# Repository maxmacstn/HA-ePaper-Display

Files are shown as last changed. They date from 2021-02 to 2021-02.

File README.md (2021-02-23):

# HA Sensor ePaper Display
E-Paper display for viewing sensor data from Home Assistant. This firmware is based on **ESPhome**, so you need to install ESPhome and compile .yaml file by yourself.

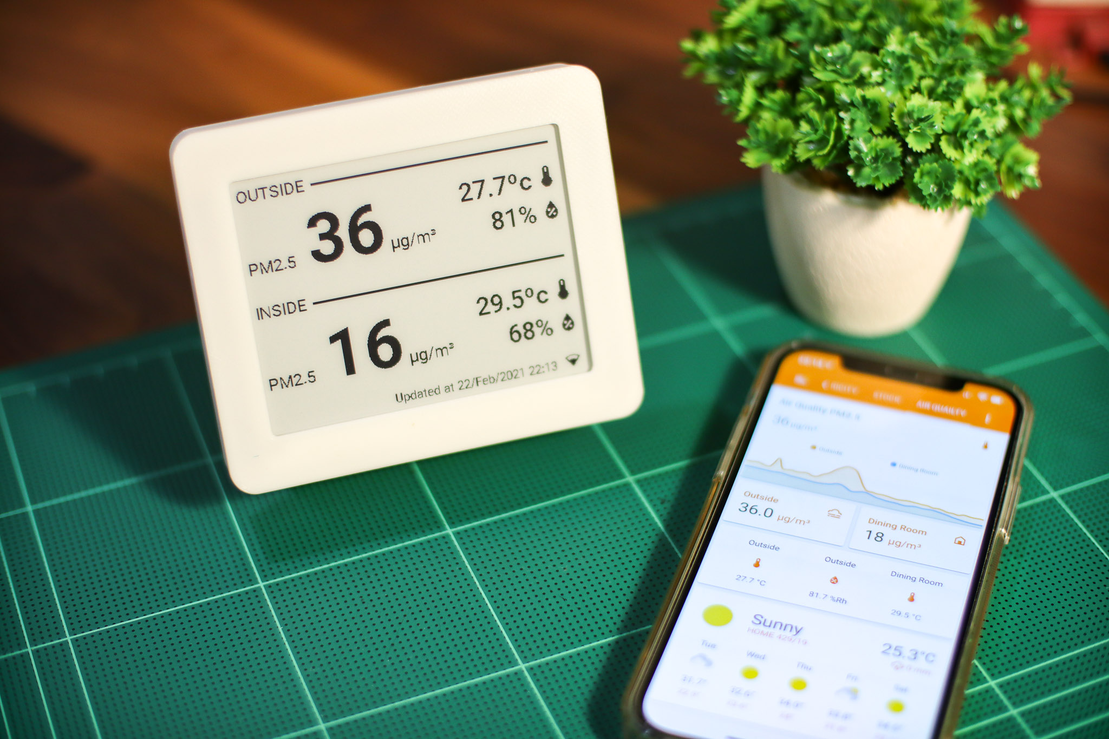
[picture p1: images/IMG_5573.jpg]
header


## Sensors data 
The display shows PM2.5 value, temperature and humidity. Each set for indoor and outdoor.

I made PM2.5 the most prominent value. Because air pollution is currently a serious problem here in my hometime. Moreover, if the value exceeds the safety threshold, a warning sign will be displayed. 

## Hardware

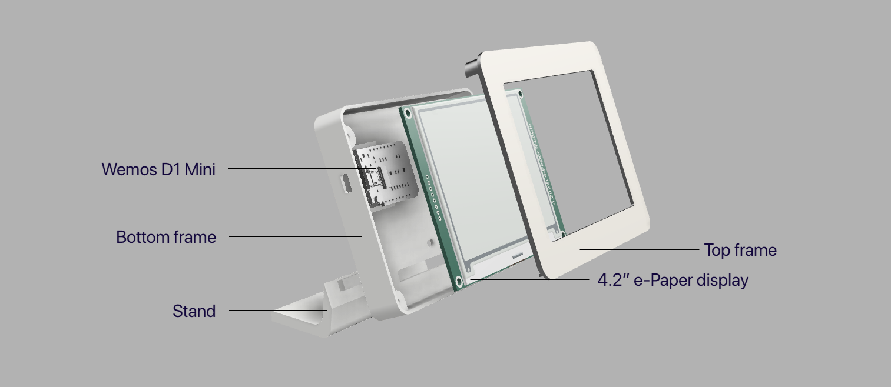
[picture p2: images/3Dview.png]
hw


### Parts:
 1. Waveshare 4.2" ePaper display
 2. ESP8266 Wemos D1 Mini
 3. 3D-Printed Case, it can be found on my thingiverse page. [https://www.thingiverse.com/thing:4772803]
 4. Stock M3 Screws from ePaper display

Note: You might need to apply some adhesives to 3d-printed parts joints, and also put some counterweight on the base to make it harder to tip over. This is my very first time designing 3D things, so it’s not perfect yet.
 
 ### Wiring: 
Connecting the display to Wemos D1 Mini is very straightforward. However, I soldered all wires diretly on both display and MCU in order to make it low-profile as much as possible.

|ePaper Display Pin| ESP8266 Pin|
|--|--|
| BUSY | GPIO16 |
| RST | GPIO04  |
| DC | GPIO12 |
| CS | GPIO15 |
| CLK | GPIO14 |
| DIN | GPIO13 |
| GND | GND |
| 3.3v | 3.3v |

## How to use?

 1. Install ESPhome on your [computer](https://esphome.io/guides/getting_started_command_line.html) or [Home Assistant Add-on](https://esphome.io/guides/getting_started_hassio.html)
 2. Copy yaml file and fonts folder to your ESPhome folder.
 3. Edit your Wi-Fi SSID/Password, sensors entity ID, etc. as your own preference.
 4. Connect hardwares together.
 5. Flash the firmware. I reccommended you to not flash via OTA.
 6. Go to Home Assistant, it should automatically discovered your espHome display. If not, add it manually using IP address via ESPhome integration.
 7. Enjoy!

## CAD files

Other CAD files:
CAD/ePaper_42_frame.f3z

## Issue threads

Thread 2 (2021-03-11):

Power Source

thjubeck, 2021-03-11:
Hey,

What is the power source for this. It looks built-in from the pictures but I did not see a schematic or part for batteries.

edit: never mind it looks like that was just static displaying.

maxmacstn, 2021-03-13:
Hello and sorry for late reply,

There is no battery in this project, it requires external 5v input. It can be either connected directly from a USB port on the side or wire a connector directly to ESP8266 board and route it out from the back as shown in the image below.

https://imgur.com/a/pbWGhIr

thjubeck, 2021-03-13:
Okay, thanks for the update. It works well! I am using this as a base for a weather station so it helped me get started.

Closed 2021-03-12.

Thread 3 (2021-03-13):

Battery

PITP2, 2021-03-13:
Hi,

great job :-)
Is it possible to powered the device with battery ?

maxmacstn, 2021-03-17:
Hi,

To make it simple, I didn't design it to operate with a battery yet. Nevertheless, with deep-sleep feature and ePaper ultra-low energy consumption, it is possible.

Duplicate of #2

Closed 2021-03-24.

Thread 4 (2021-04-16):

How display thermometer icon

ouahirog, 2021-04-16:
- file: 'fonts/materialdesignicons-webfont.ttf'
    id:  mdi_small
    size: 31
    glyphs: [
      '󰤫', # mdi-wifi-strength-alert-outline
      '󰔏', # mdi-themometer
      '󰖎' # mdi-water-percent
      ]

      it.print(375, 75 + offsetY,  id(mdi_small), TextAlign::BASELINE_CENTER, "󰔏"); //thermometer

can display the thermometer icon?
how display other icon?

maxmacstn, 2021-05-02:
In order to display other icons, you need to find a Unicode character that is corresponding to the icon in `materialdesignicons-webfont.ttf`

You can use this site to find the Unicode value of the glyphs in that font file. https://fontdrop.info/

And then find the Unicode character from the Unicode value from this site. https://unicode-table.com/
Ex. 0F0239 -> 󰈹

Finally, just use that 󰈹 character in the code where you want to display the icon as in the example in my code.

PS. Don't worry that you see a black box instead of icons in the code, it will work on the screen.

ouahirog, 2021-05-06:
It's OK,thanks!
I direct to replace '󰖎' for unicode '\uf0239'  in glyphs and print.

Closed 2021-05-06.

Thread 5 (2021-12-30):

Temp

crackers81, 2021-12-30:
How to make temperature and pollution change place?? Please help :)

maxmacstn, 2022-01-12:
If you want to change the location of the text, please try to change the first and second arguments in `it.printf()` function.
In this example, 357 and 75 is the X, Y coordinates of the temperature text on the screen.

https://github.com/maxmacstn/HA-ePaper-Display/blob/0f94a8a71bdf3f409d9ab4c76e72339bdf26f8c7/epaper-display.yaml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

Closed 2022-02-01.

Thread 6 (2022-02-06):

Use of GPIO15 causes issues flashing D1 Mini

jessedc, 2022-02-06:
Hi,

Thanks for this project, I have really enjoyed putting it together.

The README suggests connecting the screen's CS pin to GPIO15, which I found caused issues flashing the D1 Mini. The [ESPHome ESP8266 documentation](https://esphome.io/devices/esp8266.html) says `GPIO15` is a "Special Pin" used to control the boot mode and isn't available for vernal purpose GPIO.

I swapped the CS pin from `GPIO15` to `GPIO5` and things worked fine.

May I suggest modifying the README to replace `GPIO15` with `GPIO5`.

An example configuration YAML would look like this:

```yaml
spi:
  clk_pin: 14
  mosi_pin: 13

display:
  - platform: waveshare_epaper
    id: epaper_display
    cs_pin: 5
    dc_pin: 12
    busy_pin: 16
    reset_pin: 4
    model: 4.20in
    update_interval: 30s
    lambda: |-

# etc
```

maxmacstn, 2022-02-10:
Thank you very much. I'll update the readme and the code according to this suggestion.

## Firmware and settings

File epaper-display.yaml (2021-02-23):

esphome:
  name: epaper-display
  platform: ESP8266
  board: esp01_1m
  on_boot:
    priority: -10
    then:
      - delay: 10s
      - component.update: epaperdisplay

wifi:
  ssid: "YOUR_SSID_HERE"
  password: "YOUR_PASSWORD_HERE"

  # Enable fallback hotspot (captive portal) in case wifi connection fails
  ap:
    ssid: "Epaper-Display Fallback Hotspot"
    password: "123456"

captive_portal:

# Enable logging
logger:

# Enable Home Assistant API
api:

ota:
  password: "123456"


font:

  - file: 'fonts/Roboto-Medium.ttf'
    id: roboto_med_30
    size: 30
  - file: 'fonts/Roboto-Regular.ttf'
    id: footer_font
    size: 15
    glyphs:
      ['&', '@', '!', ',', '.', '"', '%', '(', ')', '+', '-', '_', ':', '°', '0',
       '1', '2', '3', '4', '5', '6', '7', '8', '9', 'A', 'B', 'C', 'D', 'E',
       'F', 'G', 'H', 'I', 'J', 'K', 'L', 'M', 'N', 'O', 'P', 'Q', 'R', 'S',
       'T', 'U', 'V', 'W', 'X', 'Y', 'Z', ' ', 'a', 'b', 'c', 'd', 'e', 'f',
       'g', 'h', 'i', 'j', 'k', 'l', 'm', 'n', 'o', 'p', 'q', 'r', 's', 't',
       'u', 'v', 'w', 'x', 'y', 'z','å', 'ä', 'ö', '/','º','µ','³']

  - file: 'fonts/Roboto-Regular.ttf'
    id: main_sensor_unit
    size: 20
    glyphs:
      ['&', '@', '!', ',', '.', '"', '%', '(', ')', '+', '-', '_', ':', '°', '0',
       '1', '2', '3', '4', '5', '6', '7', '8', '9', 'A', 'B', 'C', 'D', 'E',
       'F', 'G', 'H', 'I', 'J', 'K', 'L', 'M', 'N', 'O', 'P', 'Q', 'R', 'S',
       'T', 'U', 'V', 'W', 'X', 'Y', 'Z', ' ', 'a', 'b', 'c', 'd', 'e', 'f',
       'g', 'h', 'i', 'j', 'k', 'l', 'm', 'n', 'o', 'p', 'q', 'r', 's', 't',
       'u', 'v', 'w', 'x', 'y', 'z','å', 'ä', 'ö', '/','º','µ','³']
       
  - file: 'fonts/Roboto-Medium.ttf'
    id: sub_sensor_font
    size: 30
    glyphs:
      ['&', '@', '!', ',', '.', '"', '%', '(', ')', '+', '-', '_', ':', '°', '0',
       '1', '2', '3', '4', '5', '6', '7', '8', '9', 'A', 'B', 'C', 'D', 'E',
       'F', 'G', 'H', 'I', 'J', 'K', 'L', 'M', 'N', 'O', 'P', 'Q', 'R', 'S',
       'T', 'U', 'V', 'W', 'X', 'Y', 'Z', ' ', 'a', 'b', 'c', 'd', 'e', 'f',
       'g', 'h', 'i', 'j', 'k', 'l', 'm', 'n', 'o', 'p', 'q', 'r', 's', 't',
       'u', 'v', 'w', 'x', 'y', 'z','å', 'ä', 'ö', '/','º','µ','³']
  
  - file: 'fonts/Roboto-Bold.ttf'
    id: main_sensor_font
    size: 80
  
  - file: 'fonts/materialdesignicons-webfont.ttf'
    id:  mdi_small
    size: 31
    glyphs: [
      # Wifi
      '󰤫', # mdi-wifi-strength-alert-outline
      '󰤟', # mdi-wifi-strength-1
      '󰤢', # mdi-wifi-strength-2
      '󰤥', # mdi-wifi-strength-3
      '󰤨', # mdi-wifi-strength-4
      '󰔏', # mdi-themometer
      '󰖎' # mdi-water-percent
      ]

  - file: 'fonts/materialdesignicons-webfont.ttf'
    id:  mdi_wifi
    size: 20
    glyphs: [
      # Wifi
      '󰤫', # mdi-wifi-strength-alert-outline
      '󰤟', # mdi-wifi-strength-1
      '󰤢', # mdi-wifi-strength-2
      '󰤥', # mdi-wifi-strength-3
      '󰤨'  # mdi-wifi-strength-4

      ]

  - file: 'fonts/materialdesignicons-webfont.ttf'
    id:  mdi_med
    size: 33
    glyphs: [
      # Wifi
      '󰤫', # mdi-wifi-strength-alert-outline
      '󰤟', # mdi-wifi-strength-1
      '󰤢', # mdi-wifi-strength-2
      '󰤥', # mdi-wifi-strength-3
      '󰤨', # mdi-wifi-strength-4
      '󰀦' # mdi-alert
      ]
time:
  - platform: homeassistant
    id: homeassistant_time

#Please edit your homeassistant sensors enitity id to match yours
sensor:
  - platform: homeassistant
    entity_id: sensor.xiaomi_airpurifier_air_quality_pm25 
    id: pm25_indoor

  - platform: homeassistant
    entity_id: sensor.xiaomi_airpurifier_temp
    id: temp_indoor
  
  - platform: homeassistant
    entity_id: sensor.xiaomi_airpurifier_humidity
    id: humid_indoor
  
  - platform: homeassistant
    entity_id: sensor.temperature
    id: temp_outdoor
  
  - platform: homeassistant
    entity_id: sensor.humidity
    id: humid_outdoor
  
  
  - platform: homeassistant
    entity_id: sensor.pm2_5
    id: pm25_outdoor

  - platform: wifi_signal
    name: "WiFi Signal Sensor"
    id: wifisignal
    update_interval: 60s
    

spi:
  clk_pin: 14
  mosi_pin: 13  #DIN
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

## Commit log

2021-02-23 Add image/ Remove STL files
    STL Files can be downloaded from my thingiverse page
    [bottom_frame.stl, stand.stl, top_frame.stl]
2021-03-04 Add CAD Files
    [ePaper_42_frame.f3z]
2025-07-28 Change hardware to ESP32 C3 and add LED Light
